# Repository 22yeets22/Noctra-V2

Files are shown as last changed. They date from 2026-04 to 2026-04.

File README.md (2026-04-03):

<h1 align="center">
  Noctra Devboard
  <br>
</h1>

<h4 align="center">
A RP2350 based devboard with esp c6 mini integration for wifi + bluetooth.
</h4>
<br>

<div align="center">
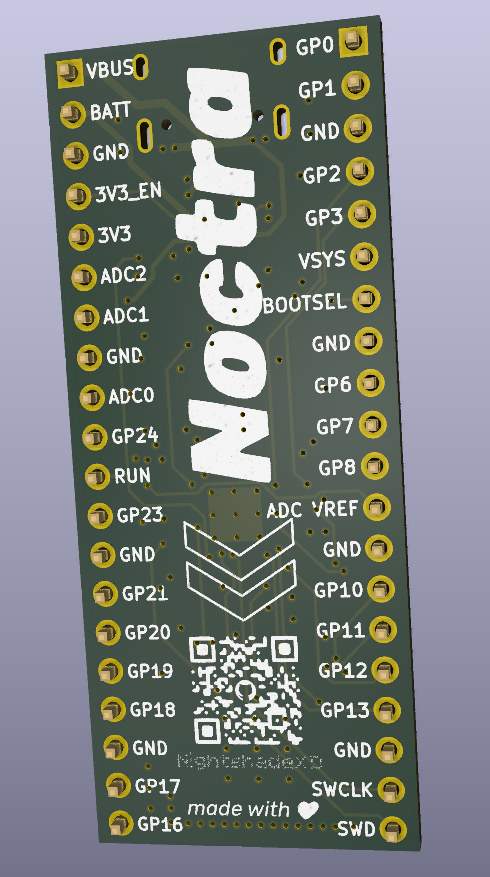
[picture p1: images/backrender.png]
Back Render


| Front Render | PCB |
| --- | --- |
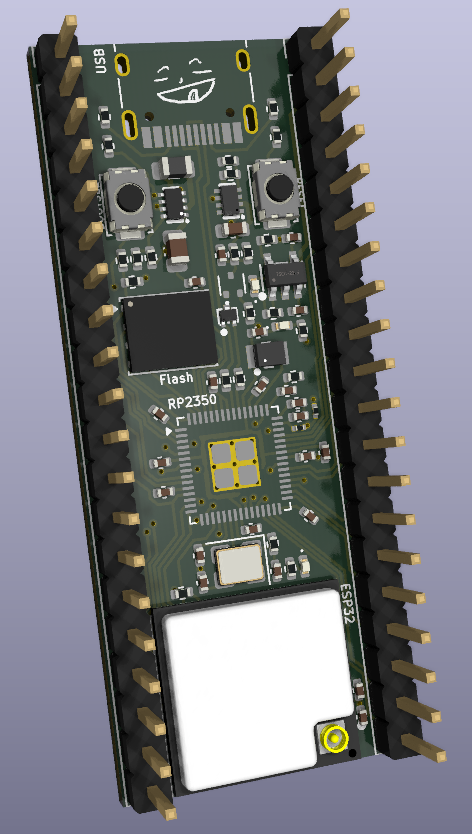
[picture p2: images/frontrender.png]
Front Render
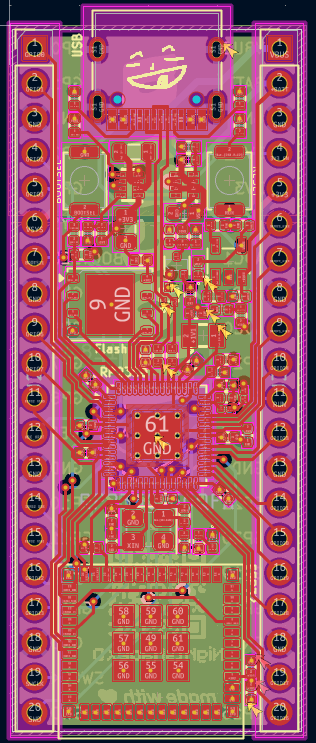
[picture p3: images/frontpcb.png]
PCB
|  |  |

</div>

<h2>Overview</h2>
- A main MCU (RP2350) for input / output pins
- A coprocessor (ESP32-C6 Mini) for wireless connectivity
- Power management (USB + battery support with battery charging)

<h3>Hardware Specs</h3>
- RP2350 microcontroller
- ESP32-C6 Mini (Wi-Fi + Bluetooth via ESP-AT)
- External 16MB flash memory (128Mbit)
- Power System
  - TPS63100 buck-boost converter: 2A, 1.6V – 5.5V, 3V3_EN pin
  - TPS2116 power mux: Auto-switch between USB and battery (~3V threshold)
  - HX4054A battery charger: 500mA + indicator LED
- USB-C, with TPD2EUSB30 ESD protection for data lines
- ADC filtering + ADC_VREF pin

<h2>How to Use</h2>
Like a normal Pico:
1. Power the board via USB-C, while holding down BOOTSEL to enter firmware writing mode.
2. Flash firmware by dragging in the firmware file.
3. Use onboard GPIO headers as you would with a standard Pico, but with wifi connectivity.

<h3>Motivation</h3>
After making my previous devboard, I wanted something with WiFi + bluetooth, so I came up with this new board. It has everything the previous board has, but better, with better power management, battery charging, and everything I could possibly want.

<h2>Firmware</h2>
Current firmware is untested, but we should be able to use the Challenger+ firmware as the topology and pins are the same. You can find the firmware in the firmware folder.

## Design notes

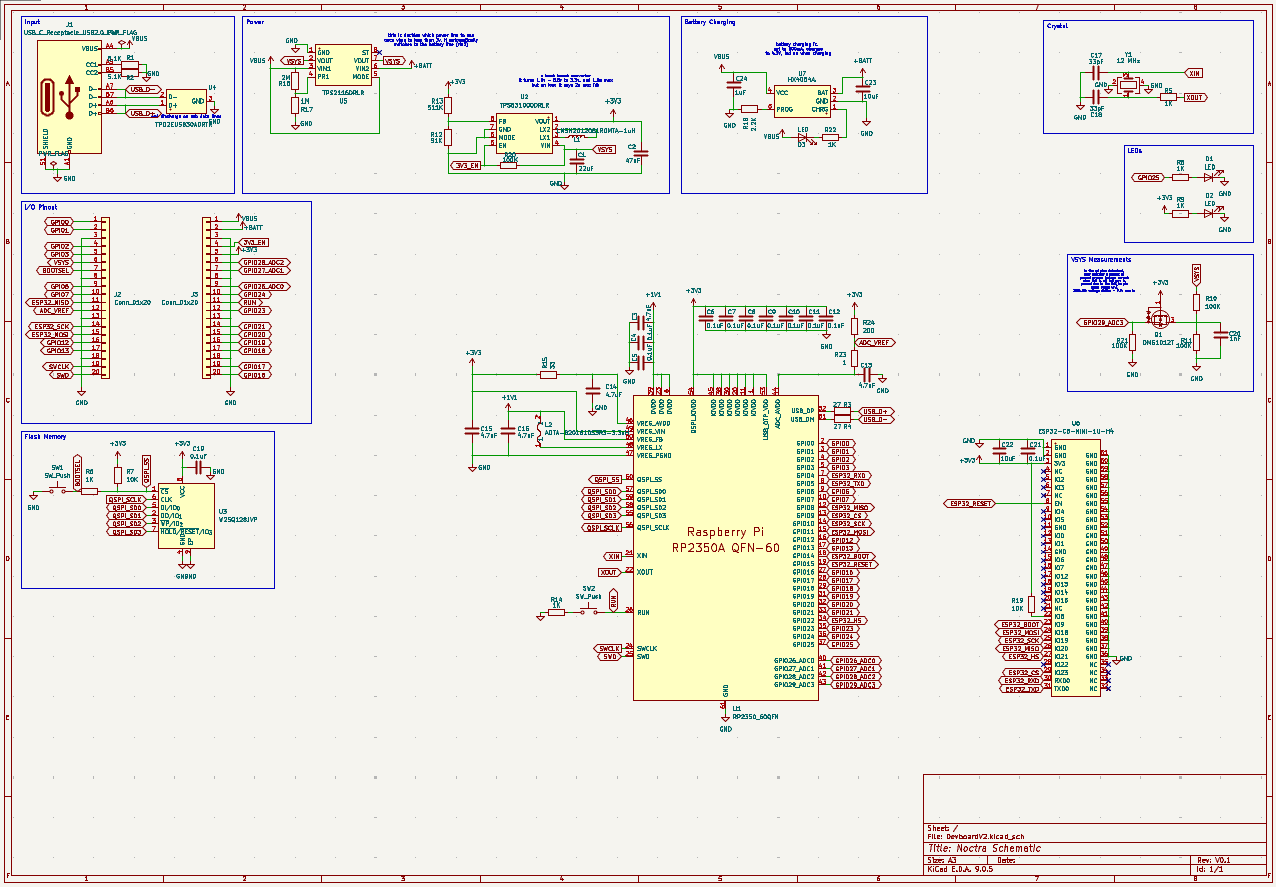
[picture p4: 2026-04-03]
images/schematic.png

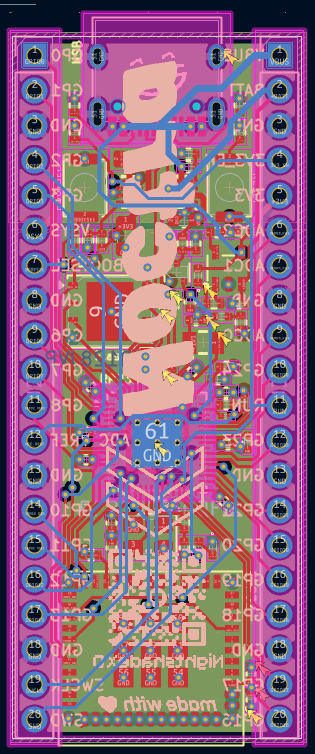
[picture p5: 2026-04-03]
images/backpcb.png

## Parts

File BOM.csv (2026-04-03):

Id | Designator | Footprint | Quantity | Designation | Supplier and ref
1 | J1 | USB_C_Receptacle_HRO_TYPE-C-31-M-12 | 1 | USB_C_Receptacle_USB2.0_14P
2 | C12,C5,C10,C21,C4,C11,C19,C6,C8,C9,C7 | C_0402_1005Metric | 11 | 0.1uF
3 | R20,R11,R21,R10 | R_0402_1005Metric | 4 | 100K
4 | L1 | L_0805_2012Metric | 1 | LMSH2012081R0MTA-1uH
5 | C15,C13,C3,C14,C16 | C_0402_1005Metric | 5 | 4.7uF
6 | C1 | C_0603_1608Metric | 1 | 22uF
7 | C2 | C_0805_2012Metric | 1 | 47uF
8 | R9,R6,R5,R14,R8,R22 | R_0402_1005Metric | 6 | 1K
9 | Y1 | Crystal_SMD_3225-4Pin_3.2x2.5mm | 1 | 12 MHz
10 | R18 | R_0402_1005Metric | 1 | 2.2K
11 | R19,R7 | R_0402_1005Metric | 2 | 10K
12 | C24 | C_0402_1005Metric | 1 | 1uF
13 | R3,R4 | R_0402_1005Metric | 2 | 27
14 | D3,D1,D2 | LED_0402_1005Metric | 3 | LED
15 | U6 | WIFIM-SMD_61P-L13.2-W12.5-P0.80 | 1 | ESP32-C6-MINI-1U-H4
16 | C20 | C_0402_1005Metric | 1 | 1nF
17 | U4 | SOT-723_L1.2-W0.8-P0.80-LS1.2-BR | 1 | TPD2EUSB30ADRTR
18 | Q1 | SOT-523 | 1 | DMG1012T
19 | C23,C22 | C_0402_1005Metric | 2 | 10uF
20 | C17,C18 | C_0402_1005Metric | 2 | 33pF
21 | L2 | IND-SMD_L2.0-W1.6_AOTA-B201610S3R3-101-T | 1 | AOTA-B201610S3R3-3.3uH
22 | U5 | SOT-583-8_L2.1-W1.6-P0.50-LS1.6-BL | 1 | TPS2116DRLR
23 | SW2,SW1 | SW_Push_SPST_NO_Alps_SKRK | 2 | SW_Push
24 | J3,J2 | PinHeader_1x20_P2.54mm_Vertical | 2 | Conn_01x20
25 | R13 | R_0402_1005Metric | 1 | 511K
26 | R12 | R_0402_1005Metric | 1 | 91K
27 | R15 | R_0402_1005Metric | 1 | 33
28 | R17 | R_0402_1005Metric | 1 | 1M
29 | R24 | R_0201_0603Metric | 1 | 200
30 | U7 | TSOT-23-5_L2.9-W1.6-P0.95-LS2.8-BL | 1 | HX4054A.
31 | R1,R2 | R_0402_1005Metric | 2 | 5.1K
32 | U2 | SOT-583-8_L2.1-W1.2-P0.50-LS1.6-BL | 1 | TPS631000DRLR
33 | R23 | R_0201_0603Metric | 1 | 1
34 | U1 | QFN-60-1EP_7x7mm_P0.4mm_EP3.4x3.4mm_ThermalVias | 1 | RP2350_60QFN
35 | R16 | R_0402_1005Metric | 1 | 2M
36 | U3 | WSON-8-1EP_6x5mm_P1.27mm_EP3.4x4.3mm | 1 | W25Q128JVP

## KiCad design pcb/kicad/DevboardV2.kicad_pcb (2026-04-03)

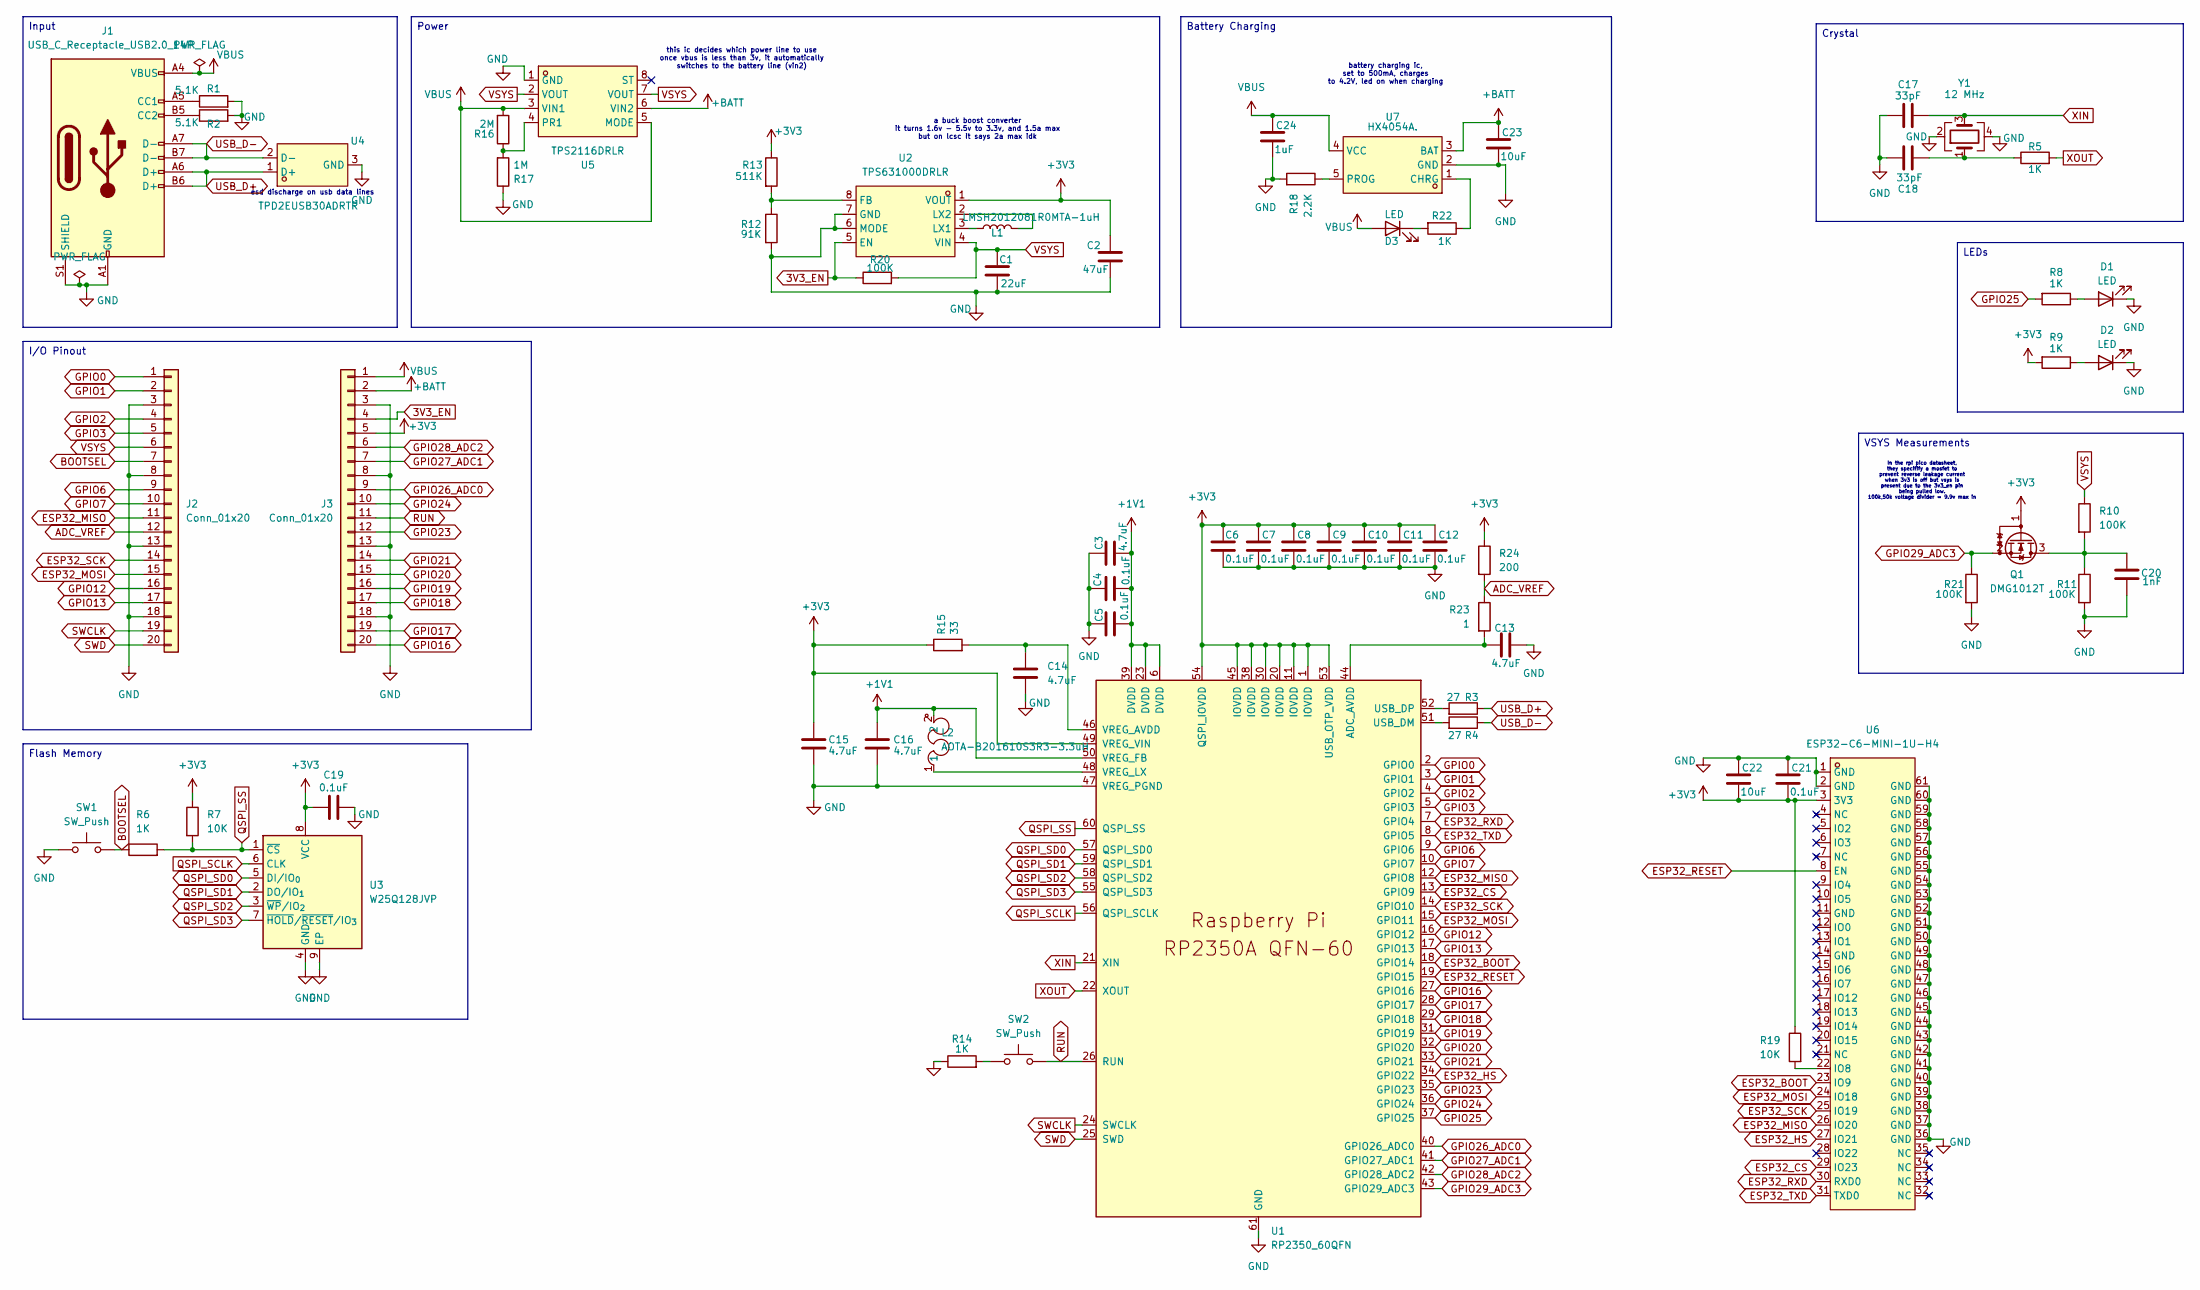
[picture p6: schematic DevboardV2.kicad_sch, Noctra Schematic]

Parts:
C1: 22uF; C_0603_1608Metric
C2: 47uF; C_0805_2012Metric
C3, C13, C14, C15, C16: 4.7uF; C_0402_1005Metric
C4, C5, C6, C7, C8, C9, C10, C11, C12, C19, C21: 0.1uF; C_0402_1005Metric
C17, C18: 33pF; C_0402_1005Metric
C20: 1nF; C_0402_1005Metric
C22, C23: 10uF; C_0402_1005Metric
C24: 1uF; C_0402_1005Metric
D1, D2, D3: LED; LED_0402_1005Metric
J1: USB_C_Receptacle_USB2.0_14P; USB_C_Receptacle_HRO_TYPE-C-31-M-12
J2, J3: Conn_01x20; PinHeader_1x20_P2.54mm_Vertical
L1: LMSH2012081R0MTA-1uH; L_0805_2012Metric
L2: AOTA-B201610S3R3-3.3uH; IND-SMD_L2.0-W1.6_AOTA-B201610S3R3-101-T; LCSC Part C42411119
Q1: DMG1012T; SOT-523
R1, R2: 5.1K; R_0402_1005Metric
R3, R4: 27; R_0402_1005Metric
R5, R6, R8, R9, R14, R22: 1K; R_0402_1005Metric
R7, R19: 10K; R_0402_1005Metric
R10, R11, R20, R21: 100K; R_0402_1005Metric
R12: 91K; R_0402_1005Metric
R13: 511K; R_0402_1005Metric
R15: 33; R_0402_1005Metric
R16: 2M; R_0402_1005Metric
R17: 1M; R_0402_1005Metric
R18: 2.2K; R_0402_1005Metric
R23: 1; R_0201_0603Metric
R24: 200; R_0201_0603Metric
SW1, SW2: SW_Push; SW_Push_SPST_NO_Alps_SKRK
U1: RP2350_60QFN; QFN-60-1EP_7x7mm_P0.4mm_EP3.4x3.4mm_ThermalVias
U2: TPS631000DRLR; SOT-583-8_L2.1-W1.2-P0.50-LS1.6-BL; LCSC Part C5219190
U3: W25Q128JVP; WSON-8-1EP_6x5mm_P1.27mm_EP3.4x4.3mm
U4: TPD2EUSB30ADRTR; SOT-723_L1.2-W0.8-P0.80-LS1.2-BR; LCSC Part C5182099
U5: TPS2116DRLR; SOT-583-8_L2.1-W1.6-P0.50-LS1.6-BL; LCSC Part C3235557
U6: ESP32-C6-MINI-1U-H4; WIFIM-SMD_61P-L13.2-W12.5-P0.80; LCSC Part C20627095
U7: HX4054A.; TSOT-23-5_L2.9-W1.6-P0.95-LS2.8-BL; LCSC Part C52952905
Y1: 12 MHz; Crystal_SMD_3225-4Pin_3.2x2.5mm

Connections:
3V3_EN: J3.4, R20.1, U2.5 (EN)
+1V1: C3.2, C4.2, C5.2, C16.1, L2.2, U1.6 (DVDD), U1.23 (DVDD), U1.39 (DVDD), U1.50 (VREG_FB)
+3V3: C2.1, C6.1, C7.1, C8.1, C9.1, C10.1, C11.1, C12.1, C15.1, C19.1, C21.2, C22.2, J3.5, Q1.1 (G), R7.1, R9.2, R13.1, R15.1, R19.1, R24.1, U1.1 (IOVDD), U1.11 (IOVDD), U1.20 (IOVDD), U1.30 (IOVDD), U1.38 (IOVDD), U1.45 (IOVDD), U1.49 (VREG_VIN), U1.53 (USB_OTP_VDD), U1.54 (QSPI_IOVDD), U2.1 (VOUT), U3.8 (VCC), U6.3 (3V3)
+BATT: C23.1, J3.2, U5.6 (VIN2), U7.3 (BAT)
ADC_VREF: J2.12, R23.1, R24.2
BOOTSEL: J2.7, R6.1, SW1.2
ESP32_BOOT: U1.18 (GPIO14), U6.23 (IO9)
ESP32_CS: U1.13 (GPIO9), U6.29 (IO23)
ESP32_HS: U1.34 (GPIO22), U6.27 (IO21)
ESP32_MISO: J2.11, U1.12 (GPIO8), U6.26 (IO20)
ESP32_MOSI: J2.15, U1.15 (GPIO11), U6.24 (IO18)
ESP32_RESET: U1.19 (GPIO15), U6.8 (EN)
ESP32_RXD: U1.7 (GPIO4), U6.30 (RXD0)
ESP32_SCK: J2.14, U1.14 (GPIO10), U6.25 (IO19)
ESP32_TXD: U1.8 (GPIO5), U6.31 (TXD0)
GND: C1.2, C2.2, C3.1, C4.1, C5.1, C6.2, C7.2, C8.2, C9.2, C10.2, C11.2, C12.2, C13.2, C14.2, C15.2, C16.2, C17.1, C18.1, C19.2, C20.2, C21.1, C22.1, C23.2, C24.2, D1.1 (K), D2.1 (K), J1.A1 (GND), J1.A12 (GND), J1.B1 (GND), J1.B12 (GND), J1.S1 (SHIELD), J2.3, J2.8, J2.13, J2.18, J3.3, J3.8, J3.13, J3.18, R1.2, R2.2, R11.2, R12.2, R14.1, R17.1, R18.2, R21.2, SW1.1, U1.47 (VREG_PGND), U1.61 (GND), U2.6 (MODE), U2.7 (GND), U3.4 (GND), U3.9 (EP), U4.3 (GND), U5.1 (GND), U6.1 (GND), U6.2 (GND), U6.36 (GND), U6.37 (GND), U6.38 (GND), U6.39 (GND), U6.40 (GND), U6.41 (GND), U6.42 (GND), U6.43 (GND), U6.44 (GND), U6.45 (GND), U6.46 (GND), U6.47 (GND), U6.48 (GND), U6.49 (GND), U6.50 (GND), U6.51 (GND), U6.52 (GND), U6.53 (GND), U6.54 (GND), U6.55 (GND), U6.56 (GND), U6.57 (GND), U6.58 (GND), U6.59 (GND), U6.60 (GND), U6.61 (GND), U7.2 (GND), Y1.2, Y1.4
GPIO0: J2.1, U1.2 (GPIO0)
GPIO1: J2.2, U1.3 (GPIO1)
GPIO2: J2.4, U1.4 (GPIO2)
GPIO3: J2.5, U1.5 (GPIO3)
GPIO6: J2.9, U1.9 (GPIO6)
GPIO7: J2.10, U1.10 (GPIO7)
GPIO12: J2.16, U1.16 (GPIO12)
GPIO13: J2.17, U1.17 (GPIO13)
GPIO16: J3.20, U1.27 (GPIO16)
GPIO17: J3.19, U1.28 (GPIO17)
GPIO18: J3.17, U1.29 (GPIO18)
GPIO19: J3.16, U1.31 (GPIO19)
GPIO20: J3.15, U1.32 (GPIO20)
GPIO21: J3.14, U1.33 (GPIO21)
GPIO23: J3.12, U1.35 (GPIO23)
GPIO24: J3.10, U1.36 (GPIO24)
GPIO25: R8.2, U1.37 (GPIO25)
GPIO26_ADC0: J3.9, U1.40 (GPIO26_ADC0)
GPIO27_ADC1: J3.7, U1.41 (GPIO27_ADC1)
GPIO28_ADC2: J3.6, U1.42 (GPIO28_ADC2)
GPIO29_ADC3: Q1.2 (S), R21.1, U1.43 (GPIO29_ADC3)
unnamed: C18.2, R5.1, Y1.1
unnamed: D1.2 (A), R8.1
unnamed: D2.2 (A), R9.1
unnamed: D3.1 (K), R22.2
unnamed: J1.A5 (CC1), R1.1
unnamed: J1.B5 (CC2), R2.1
unnamed: C20.1, Q1.3 (D), R10.2, R11.1
unnamed: R14.2, SW2.2
unnamed: C13.1, R23.2, U1.44 (ADC_AVDD)
unnamed: R4.2, U1.51 (USB_DM)
unnamed: R3.2, U1.52 (USB_DP)
unnamed: C14.1, R15.2, U1.46 (VREG_AVDD)
unnamed: L2.1, U1.48 (VREG_LX)
unnamed: R12.1, R13.2, U2.8 (FB)
unnamed: L1.2, U2.3 (LX1)
unnamed: L1.1, U2.2 (LX2)
unnamed: R16.1, R17.2, U5.4 (PR1)
unnamed: R19.2, U6.22 (IO8)
unnamed: R22.1, U7.1 (CHRG)
unnamed: R18.1, U7.5 (PROG)
QSPI_SCLK: U1.56 (QSPI_SCLK), U3.6 (CLK)
QSPI_SD0: U1.57 (QSPI_SD0), U3.5 (DI/IO_{0})
QSPI_SD1: U1.59 (QSPI_SD1), U3.2 (DO/IO_{1})
QSPI_SD2: U1.58 (QSPI_SD2), U3.3 (~WP/IO_{2})
QSPI_SD3: U1.55 (QSPI_SD3), U3.7 (~HOLD/~RESET/IO_{3})
QSPI_SS: R6.2, R7.2, U1.60 (QSPI_SS), U3.1 (~CS)
RUN: J3.11, SW2.1, U1.26 (RUN)
SWCLK: J2.19, U1.24 (SWCLK)
SWD: J2.20, U1.25 (SWD)
USB_D+: J1.A6 (D+), J1.B6 (D+), R3.1, U4.1 (D+)
USB_D-: J1.A7 (D-), J1.B7 (D-), R4.1, U4.2 (D-)
VBUS: C24.1, D3.2 (A), J1.A4 (VBUS), J1.A9 (VBUS), J1.B4 (VBUS), J1.B9 (VBUS), J3.1, R16.2, U5.3 (VIN1), U5.5 (MODE), U7.4 (VCC)
VSYS: C1.1, J2.6, R10.1, R20.2, U2.4 (VIN), U5.2 (VOUT), U5.7 (VOUT)
XIN: C17.2, U1.21 (XIN), Y1.3
XOUT: R5.2, U1.22 (XOUT)

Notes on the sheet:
this ic decides which power line to use once vbus is less than 3v, it automatically switches to the battery line (vin2)
esd discharge on usb data lines
battery charging ic, set to 500mA, charges to 4.2V, led on when charging
In the rpi pico datasheet, they specifify a mosfet to prevent reverse leakage current when 3v3 is off but vsys is present due to the 3v3_en pin being pulled low. 100k,50k voltage divider = 9.9v max in
a buck boost converter it turns 1.6v - 5.5v to 3.3v, and 1.5a max but on lcsc it says 2a max idk
Power
Input
LEDs
Battery Charging
VSYS Measurements
Flash Memory
I/O Pinout
Crystal

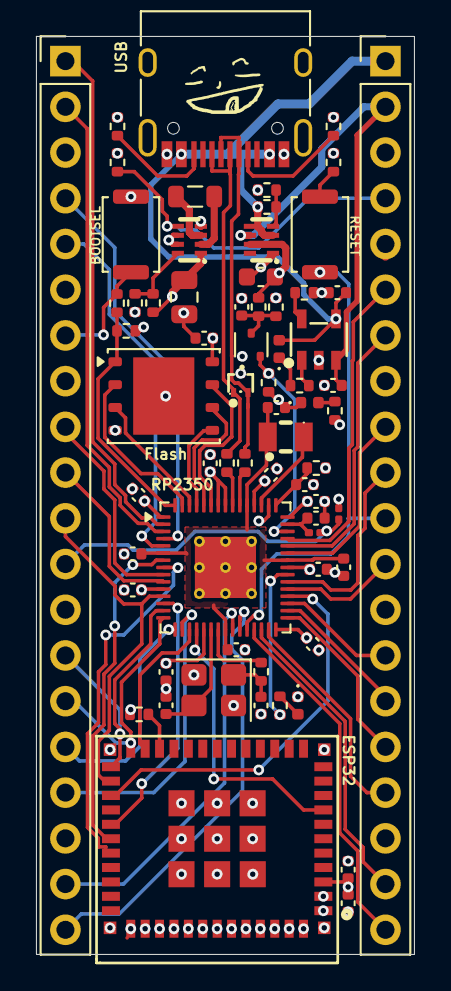
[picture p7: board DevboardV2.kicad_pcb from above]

Board: 4 copper layers, 21.0 x 51.0 mm, 67 parts (0 on the bottom side), 72 nets.
